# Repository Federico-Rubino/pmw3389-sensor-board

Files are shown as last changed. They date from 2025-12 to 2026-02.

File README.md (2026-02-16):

View this project on [CADLAB.io](https://cadlab.io/project/29776). 

# pmw3389-sensor-board

The repo contain the KiCad project for a custom PCB to use the PixArt pmw3389dm-T3QU. The board needs either 5V and 3V to be used.

# Usage

Clone this repo on your local machine and open the project using KiCad.

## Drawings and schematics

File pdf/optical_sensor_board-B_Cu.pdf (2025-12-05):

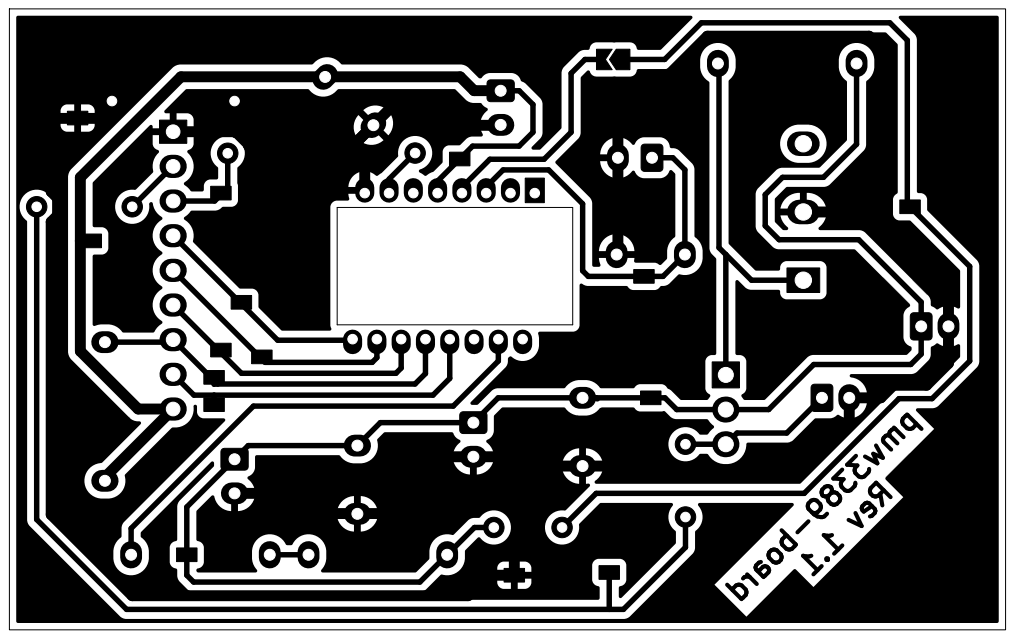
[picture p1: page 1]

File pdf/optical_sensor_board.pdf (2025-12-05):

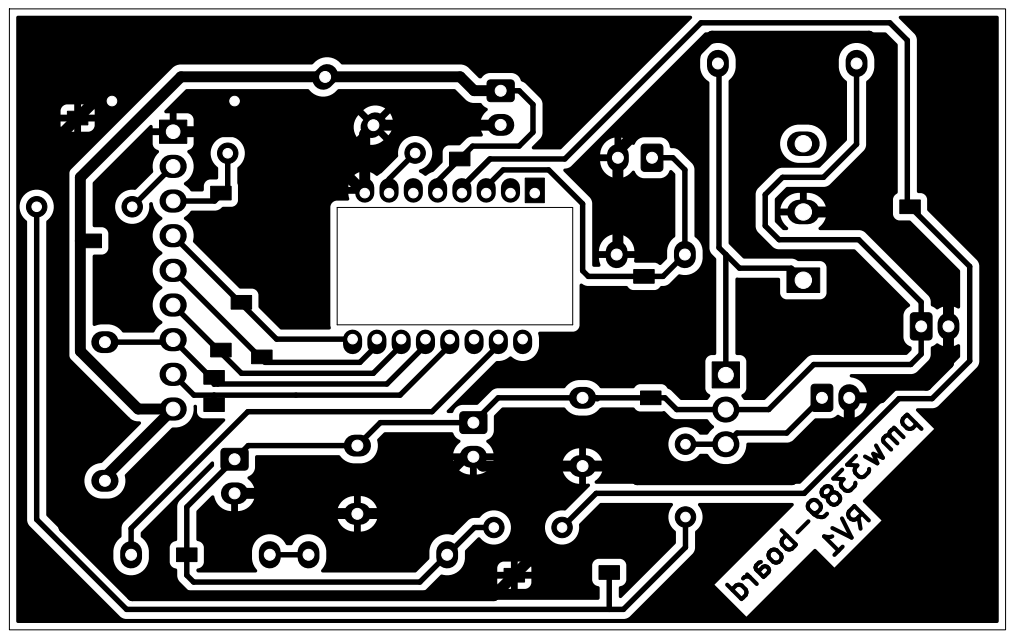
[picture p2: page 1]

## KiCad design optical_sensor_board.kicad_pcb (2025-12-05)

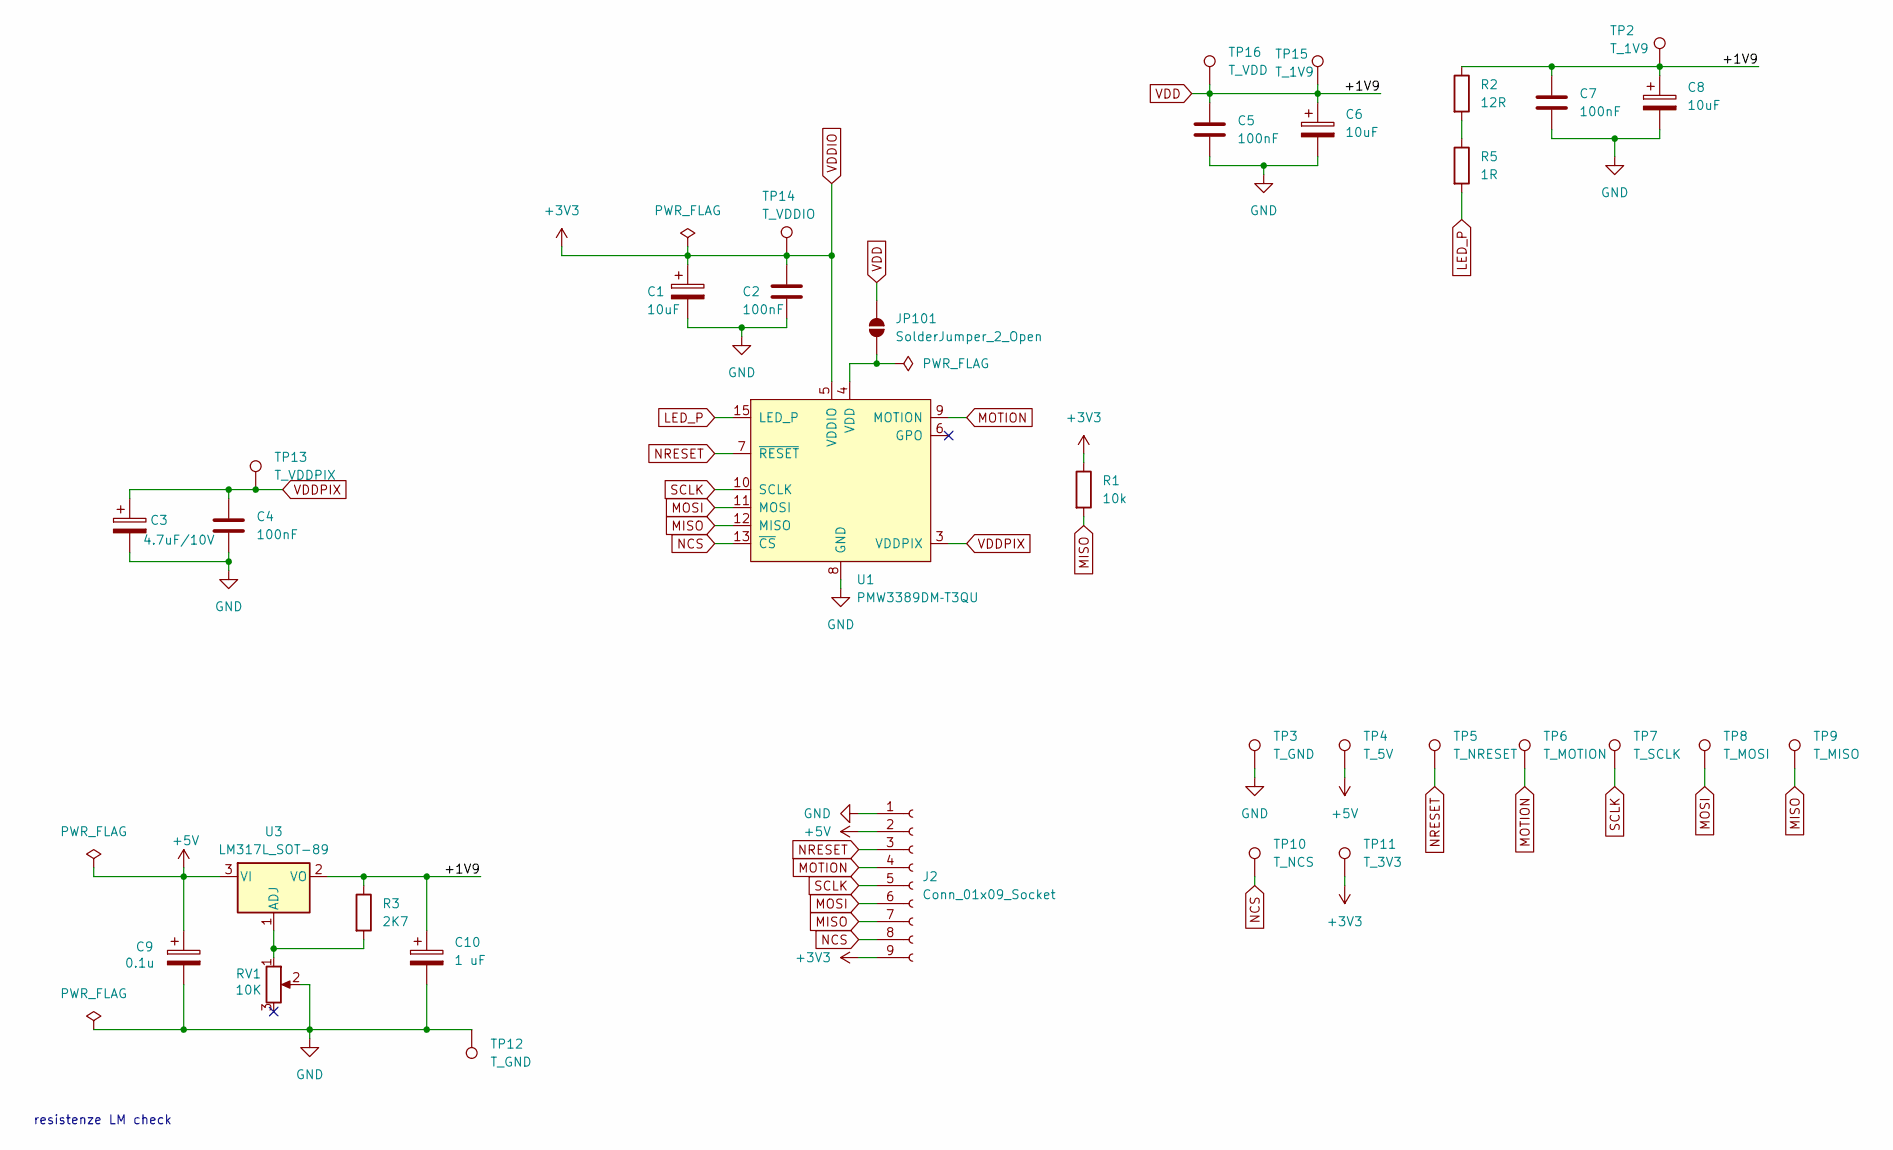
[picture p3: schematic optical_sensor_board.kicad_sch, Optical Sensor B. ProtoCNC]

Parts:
C1, C6, C8: 10uF; LargePad_CP_Radial_D6.3mm_P2.50mm
C2, C4, C5, C7: 100nF; LargePad_C_Disc_D5.0mm_W2.5mm_P5.00mm
C3: 4.7uF/10V; LargePad_CP_Radial_D6.3mm_P2.50mm
C9: 0.1u; LargePad_CP_Radial_D5.0mm_P2.00mm
C10: 1 uF; LargePad_CP_Radial_D5.0mm_P2.00mm
J2: Conn_01x09_Socket; LargePad_PinHeader_1x09_P2.54mm_Vertical
JP101: SolderJumper_2_Open; SolderJumper-2_P1.3mm_Open_TrianglePad1.0x1.5mm
R1: 10k; LargePad_R_Axial_DIN0207_L6.3mm_D2.5mm_P10.16mm_Horizontal
R2: 12R; LargePad_R_Axial_DIN0207_L6.3mm_D2.5mm_P10.16mm_Horizontal
R3: 2K7; LargePad_R_Axial_DIN0207_L6.3mm_D2.5mm_P10.16mm_Horizontal
R5: 1R; LargePad_R_Axial_DIN0207_L6.3mm_D2.5mm_P10.16mm_Horizontal
RV1: 10K; LargerPad_P160
TP2, TP15: T_1V9; TestPoint_Pad_1.0x1.0mm
TP3, TP12: T_GND; TestPoint_Pad_1.0x1.0mm
TP4: T_5V; TestPoint_Pad_1.0x1.0mm
TP5: T_NRESET; TestPoint_Pad_1.0x1.0mm
TP6: T_MOTION; TestPoint_Pad_1.0x1.0mm
TP7: T_SCLK; TestPoint_Pad_1.0x1.0mm
TP8: T_MOSI; TestPoint_Pad_1.0x1.0mm
TP9: T_MISO; TestPoint_Pad_1.0x1.0mm
TP10: T_NCS; TestPoint_Pad_1.0x1.0mm
TP11: T_3V3; TestPoint_Pad_1.0x1.0mm
TP13: T_VDDPIX; TestPoint_Pad_1.0x1.0mm
TP14: T_VDDIO; TestPoint_Pad_1.0x1.0mm
TP16: T_VDD; TestPoint_Pad_1.0x1.0mm
U1: PMW3389DM‐T3QU; LargePad_PXI-DIP-16
U3: LM317L_SOT-89; TO-220-3_Vertical

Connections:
+5V: C9.1, J2.2, TP4.1, U3.3 (VI)
GND: C1.2, C2.2, C3.2, C4.2, C5.2, C6.2, C7.2, C8.2, C9.2, C10.2, J2.1, RV1.2, TP3.1, TP12.1, U1.8 (GND)
LED_P: R5.2, U1.15 (LED_P)
MISO: J2.7, R1.2, TP9.1, U1.12 (MISO)
MOSI: J2.6, TP8.1, U1.11 (MOSI)
MOTION: J2.4, TP6.1, U1.9 (MOTION)
NCS: J2.8, TP10.1, U1.13 (~CS)
NRESET: J2.3, TP5.1, U1.7 (~RESET)
unnamed: JP101.2 (B), U1.4 (VDD)
unnamed: R2.2, R5.1
unnamed: R3.2, RV1.1, U3.1 (ADJ)
SCLK: J2.5, TP7.1, U1.10 (SCLK)
VDD: C5.1, C6.1, C7.1, C8.1, C10.1, JP101.1 (A), R2.1, R3.1, TP2.1, TP15.1, TP16.1, U3.2 (VO)
VDDIO: C1.1, C2.1, J2.9, R1.1, TP11.1, TP14.1, U1.5 (VDDIO)
VDDPIX: C3.1, C4.1, TP13.1, U1.3 (VDDPIX)

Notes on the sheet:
resistenze LM check

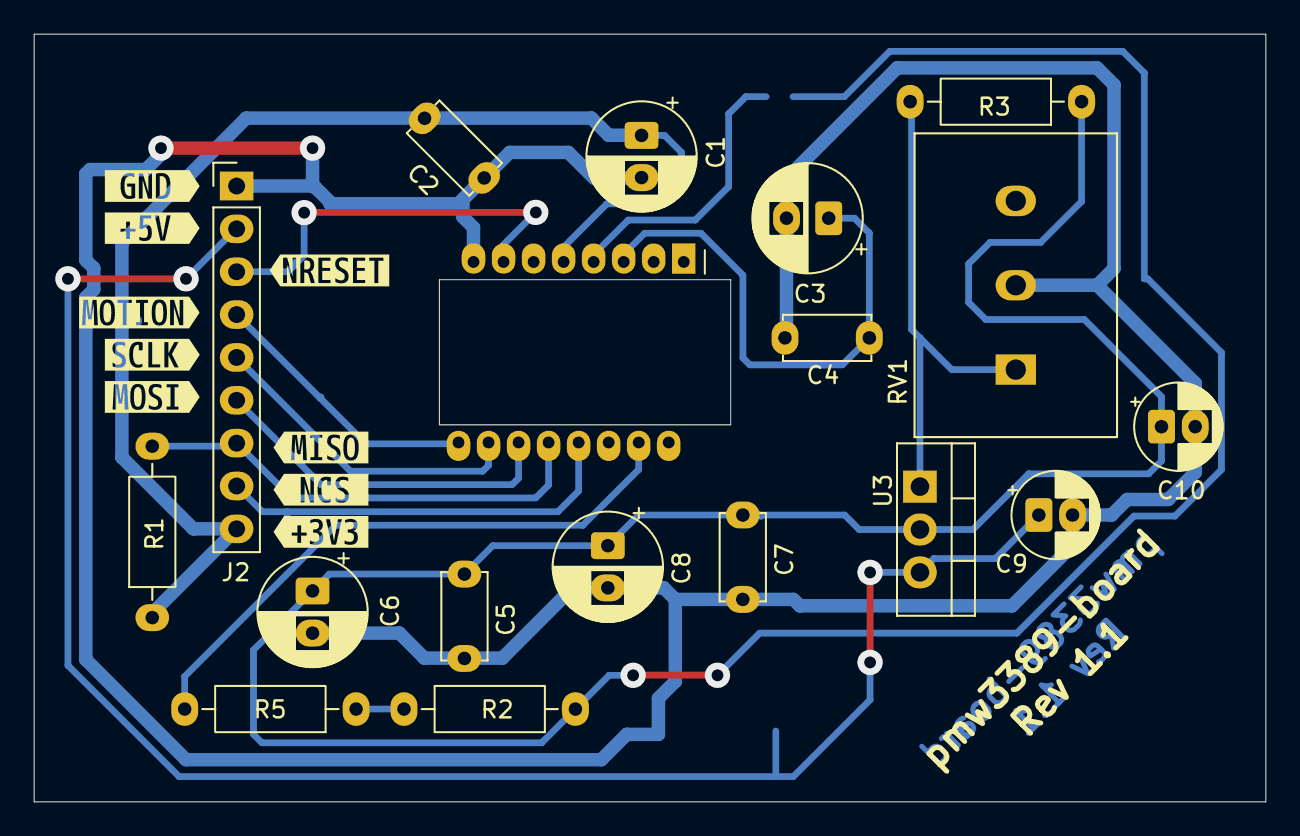
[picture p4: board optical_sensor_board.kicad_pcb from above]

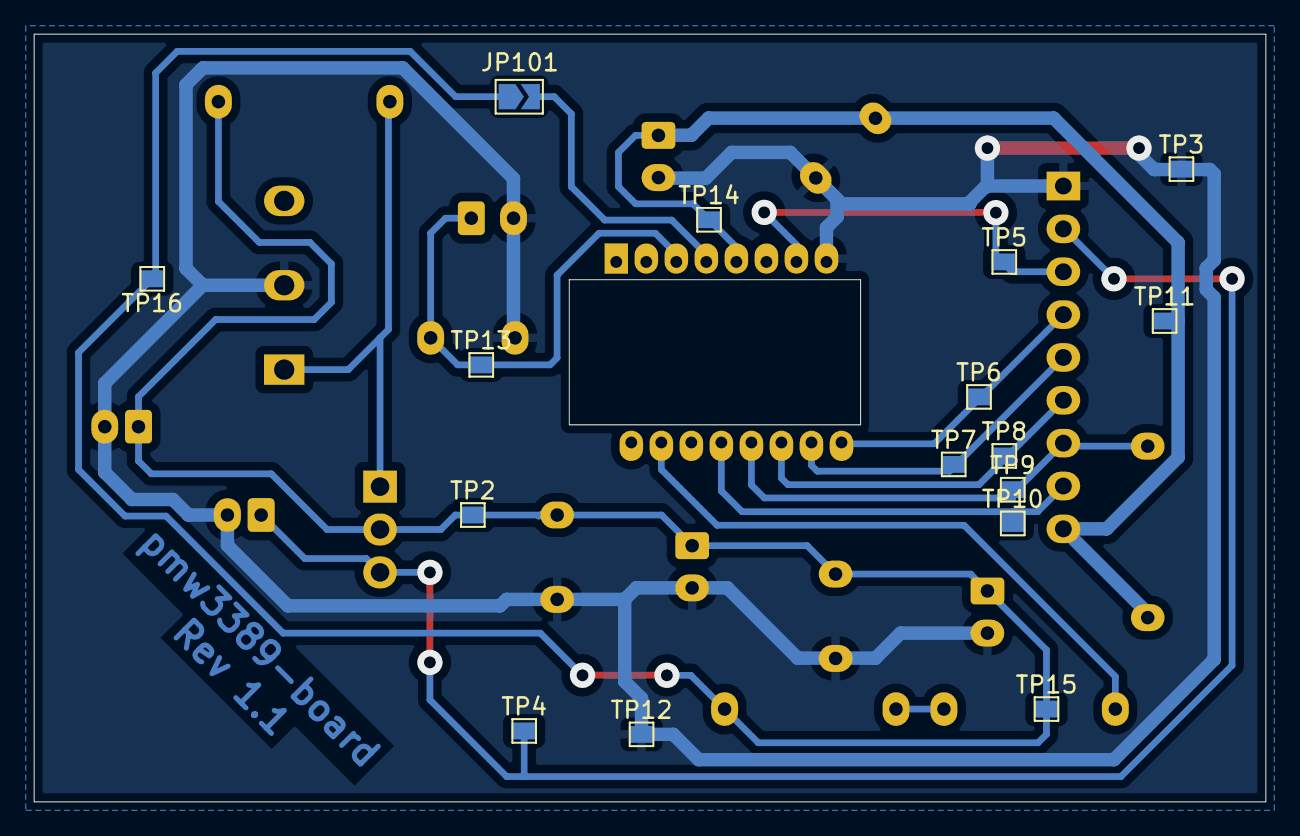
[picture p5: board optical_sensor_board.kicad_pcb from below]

Board: 2 copper layers, 73.0 x 45.5 mm, 43 parts (16 on the bottom side), 15 nets.

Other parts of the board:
kibuzzard-692FFC6C: G***; kibuzzard-692FFC6C
kibuzzard-692FFFAD: G***; kibuzzard-692FFFAD
kibuzzard-692FFFD7: G***; kibuzzard-692FFFD7
kibuzzard-692FFFF6: G***; kibuzzard-692FFFF6
kibuzzard-69300A7E: G***; kibuzzard-69300A7E
kibuzzard-69300AAA: G***; kibuzzard-69300AAA
kibuzzard-69300B41: G***; kibuzzard-69300B41
kibuzzard-69300011: G***; kibuzzard-69300011
kibuzzard-69303597: G***; kibuzzard-69303597

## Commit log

2025-12-01 Aggiunta copper-area + modifiche a schematico e master
    Design:
    - Spostate le tracce sul bottom e i ponti sul top layer
    - Aggiunta la Copper Area sul bottom layer
    - Sistemate le serigrafie
    Schematico:
    - Corretti gli errori del ERC aggiungendo i PWR_FLAG
    - Spostati i componenti per far si che si veda almeno un pezzettino di filo
    Progetto:
    - Aggiunta la libreria dei footprint
    [optical_sensor_board.kicad_pcb, optical_sensor_board.kicad_sch]
2025-12-01 add potentiometer in LM317 circuit
    [optical_sensor_board.kicad_sch]
2025-12-01 potentiometer footprint + potentiometer routing
    [optical_sensor_board.kicad_pcb, optical_sensor_board.kicad_sch]
2025-12-01 copper area
    [optical_sensor_board.kicad_pcb, optical_sensor_board.kicad_sch]
2025-12-01 pmw3386Board RV1 text
    [optical_sensor_board.kicad_pcb]
2025-12-01 copper GND plane
    [optical_sensor_board.kicad_pcb]
2025-12-01 TestPoint in Schematic
    [optical_sensor_board.kicad_pcb, optical_sensor_board.kicad_sch]
2025-12-02 add Footprint TestPoint
    [optical_sensor_board.kicad_sch]
2025-12-02 start TestPoint routing
    [optical_sensor_board.kicad_pcb, optical_sensor_board.kicad_sch]
2025-12-02 TestPoint routed
    [optical_sensor_board.kicad_pcb, optical_sensor_board.kicad_sch]
2025-12-03 Modificato graficamente lo schematico + moidifiche al PCB
    - Sistemato graficamente lo schema
    - Corretto il testo del PCB
    [optical_sensor_board.kicad_pcb, optical_sensor_board.kicad_sch]
2025-12-03 SilkScreen pin name
    [optical_sensor_board.kicad_pcb]
2025-12-03 Correct trimmer footprint
    [optical_sensor_board.kicad_pcb]
2025-12-03 modified SilkScreen for pin MOTION
    [optical_sensor_board.kicad_pcb]
2025-12-05 New potentiometer footprint + pin Labels
2025-12-05 Modified some componets position
    [optical_sensor_board.kicad_pcb]
2025-12-05 Re-runned DEC and corrected some errors
    [optical_sensor_board.kicad_pcb]
2025-12-05 drc ok + pdf for PnP
    [optical_sensor_board.kicad_pcb]
2025-12-05 Added a solder-jumer in series to the PS of the chip
    [optical_sensor_board.kicad_pcb, optical_sensor_board.kicad_sch]
2025-12-05 Modified some traks of the PCB + exported new PDF for mastering
    [optical_sensor_board.kicad_pcb, optical_sensor_board.kicad_sch]
